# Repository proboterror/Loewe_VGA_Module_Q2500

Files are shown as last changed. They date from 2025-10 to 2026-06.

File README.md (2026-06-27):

# Loewe TVs Q2500 VGA Module
Recreation of VGA module PCB for Loewe TVs with Q2500M chassis.

Project based on work done by Oelii from [circuit-board.de/forum](https://circuit-board.de/forum/index.php/Thread/28516-WIP-DIY-Loewe-VGA-Modul-Q2500/)

Schematic recreated from the scratch in KiCad. PCB based on Oelii's layout and verified with Desing/Electrical Rules Checker tools.<br>
Components footprints replaced with KiCad standard ones.

## Chassis compatibility
Unverified, obtained from post by djcalle on [circuit-board.de/forum](https://circuit-board.de/forum/index.php/Thread/28516-WIP-DIY-Loewe-VGA-Modul-Q2500/?postID=906980#post906980):
- Q23, Q24, Q25 can accept VGA cards.
- Q25 and Q24 use the same VGA card (only 2 differences: cable length and 150R termination on RGB lines.)
- Q25 seems to be inconsistent with VGA card compatibility.
- Q24 seems consistent with vga card compatibility.
- Q23 uses its own [different card](https://github.com/proboterror/Loewe_VGA_Module_Q2300).

## EDID option
For widescreen TVs [EDID](https://en.wikipedia.org/wiki/Extended_Display_Identification_Data) EEPROM option can be installed and flashed, helping to automatically add 848x480@60Hz (CVT) default widescreen resolution.

Original schematic from [Loewe Q2500-M chassis service manual](doc/Q2500-M/Loewe%20Q2500M%20Service%20Manual.pdf)
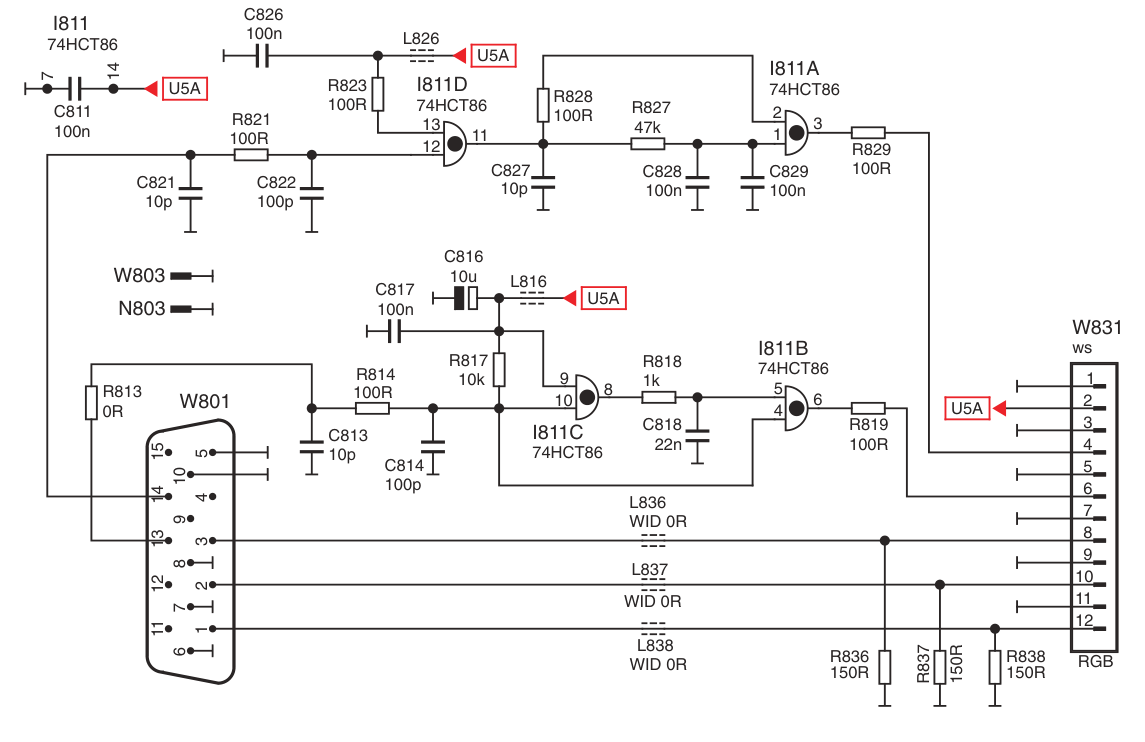
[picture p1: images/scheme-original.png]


Recreated schematic and PCB
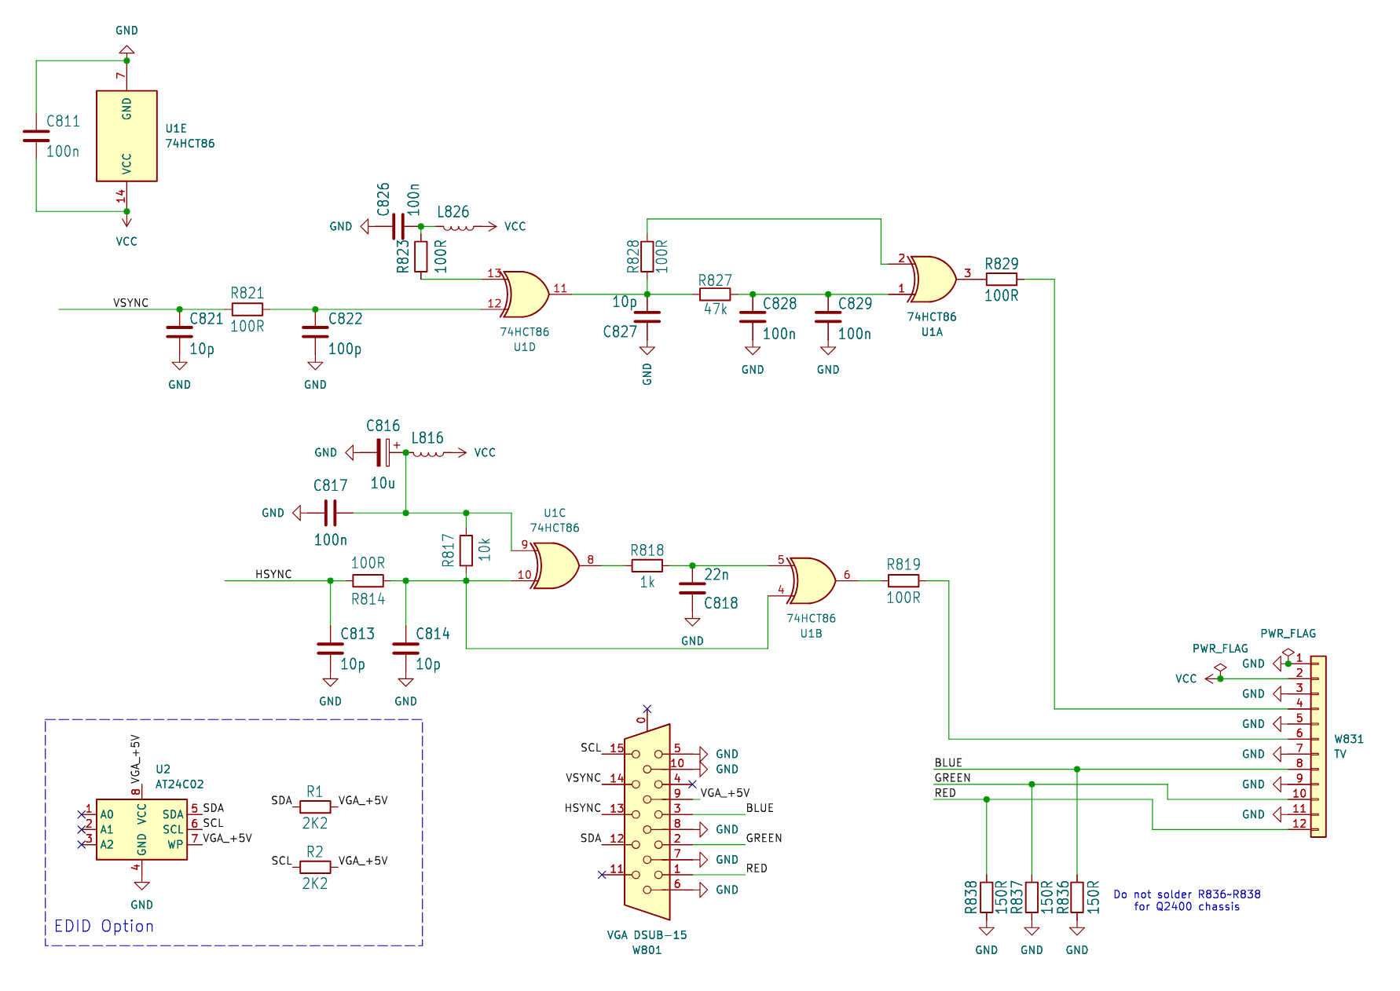
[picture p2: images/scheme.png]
scheme

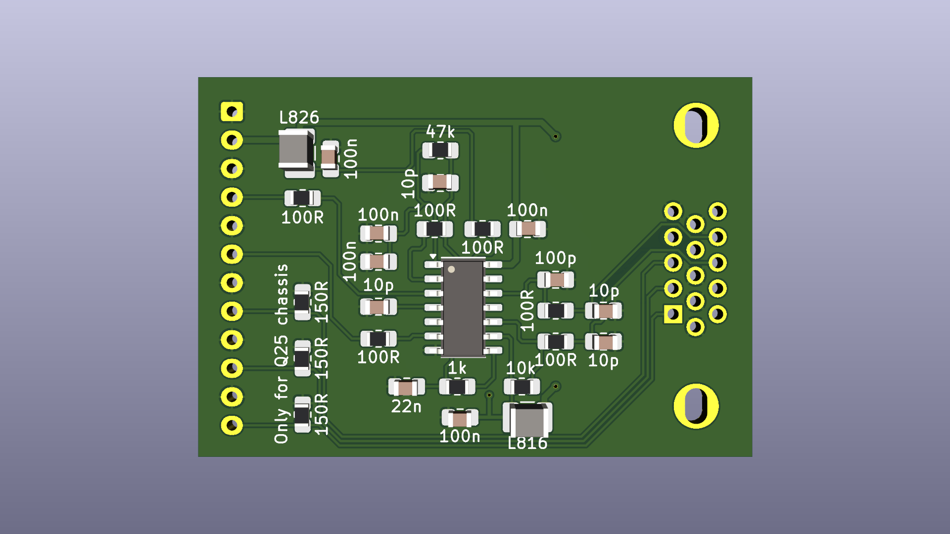
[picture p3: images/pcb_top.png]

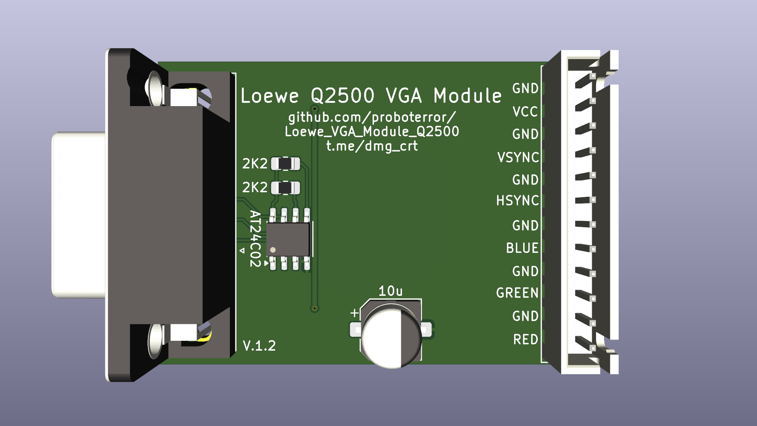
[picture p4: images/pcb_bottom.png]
pcb_bottom

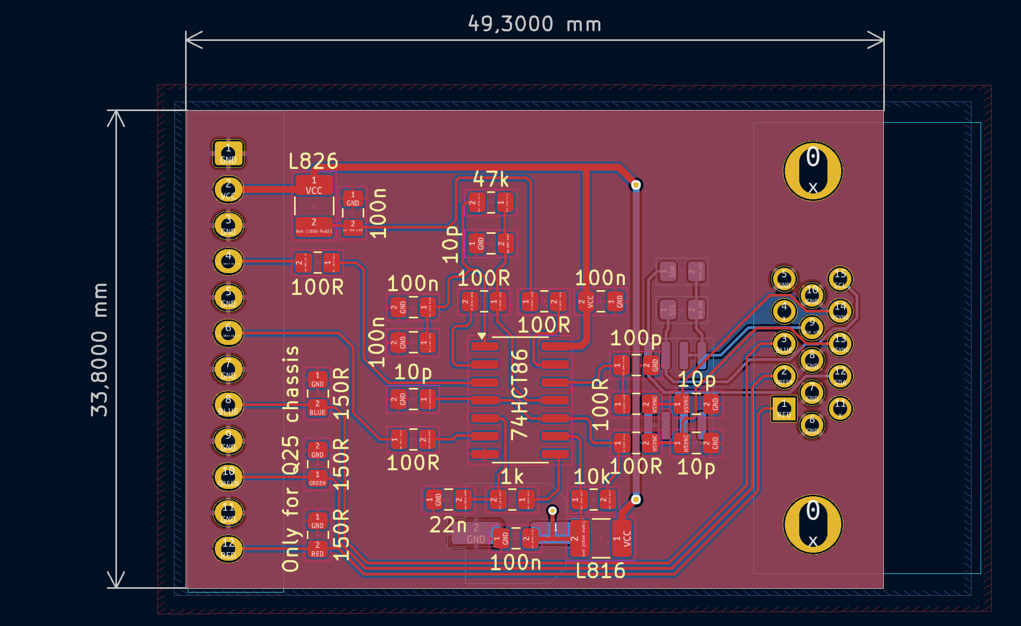
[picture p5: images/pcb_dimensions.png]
pcb_dimensions


## Bill of materials
|Reference|Value|Footprint|Qty|
|-----|-----|-----|-----|
|C811,C817,C826,C828,C829|100n|0805|5|
|C813,C814,C821,C827|10p|0805|4|
|C816|10u|0805|1|
|C818|22n|0805|1|
|C822|100p|0805|1|
|L816,L826|1210(3225)|4.7uH|2|
|R814,R819,R821,R823,R828,R829|100R|0805|6|
|R817|10k|0805|1|
|R818|1k|0805|1|
|R827|47k|0805|1|
|R836,R837,R838|150R|0805|3|
|I811|74HCT86|SO-14|1|
|W801|VGA DSUB-15<br>Edge pin offset 8.35mm<br>Mounting holes offset 10.89mm ||1|
|W831|JST XH 2.54 12 Pin||1|
|U2|AT24C02 (EDID option)|SOIC-8|1|
|R1,R2|2K2 (EDID option)|0805|2|

## Order boards from manufacturer
Send "gerbers" folder content packed to zip archive.

## Build Notes
AT24C02 EEPROM and R1,R2 are EDID option, useful for connection widescreen models to PC/VGA.

L816 and L826 SMD 1210(3225) inductors value are unknown; 4.7uH in Q2300 VGA module schematic; can be replaced with 0R resistor.

W831 connector originally is Molex 22-23-2121. Probably can be replaced with XH 2.54 12 pin connectors / cables, note pins step 2.5/254 mm.<br>
Pay attention on cable connectors type: same direction or reverse direction.<br>
12 pin 50 cm cable are required for Q25 chassis, 30 cm cable for Q24 chassis. For Q23 chassis, two 10 pin cables are required.

**Double-check ground and VCC connection on VGA module PCB and TV chassis before soldering 12-pin W831 connector and power on.**

## EDID ROM
[Extended Display Identification Data (EDID)](https://en.wikipedia.org/wiki/Extended_Display_Identification_Data) ROM sends display info to PC over VGA [I2C](https://en.wikipedia.org/wiki/I2C) [DDC (Display Data Channel)](https://en.wikipedia.org/wiki/Display_Data_Channel), such as supported / default resolutions, supported frequency ranges, physical dimensions and display name.

Standard VGA resolutions 640x400@70Hz and 640x480@60Hz marked as supported.<br>
Added custom default resolution 848x480@60Hz.<br>
Added modeline generated with [CVT](doc/VESA-CVT-1.2.pdf) formulas.<br>
Display reported as "Loewe CRT".

Generated [edid.bin](EDID/edid.bin) can be in-system programmed to AT24C02 EEPROM with CH341 (I2C) programmer, 8 pin chip clip and NeoProgrammer V2.2.0.10:
"IC/I2C/Generic/_24C02 [3.3V]" or "Detect", "File/Open" .bin, "Write IC" (Erase, Blank Check, Write, Verify).

[EDID 1.3](doc/VESA-EEDID-A1.pdf) display description ROM image in raw .hex format generated with [generate_edid.py](EDID/generate_edid.py) script.

Generate edid.hex:
```
python generate_edid.py > edid.hex
```
Convert raw .hex to .bin:
```
type edid.hex | xxd -r -p > edid.bin
```
To view generated display description:
```
edid-decode edid.bin
```

Conservative / more compatible custom modeline included by default:
```
Modeline "848x480_60" 31.75  848 864 944 1024  480 483 493 517 -hsync +vsync
```
Alternative modeline generated with cvt utility can be selected in generate_edid.py:
```
cvt 848 480 60
Modeline "848x480_60" 31.50  848 872 952 1056  480 483 493 500 -hsync +vsync
```

## Install
Q2400 chassis:
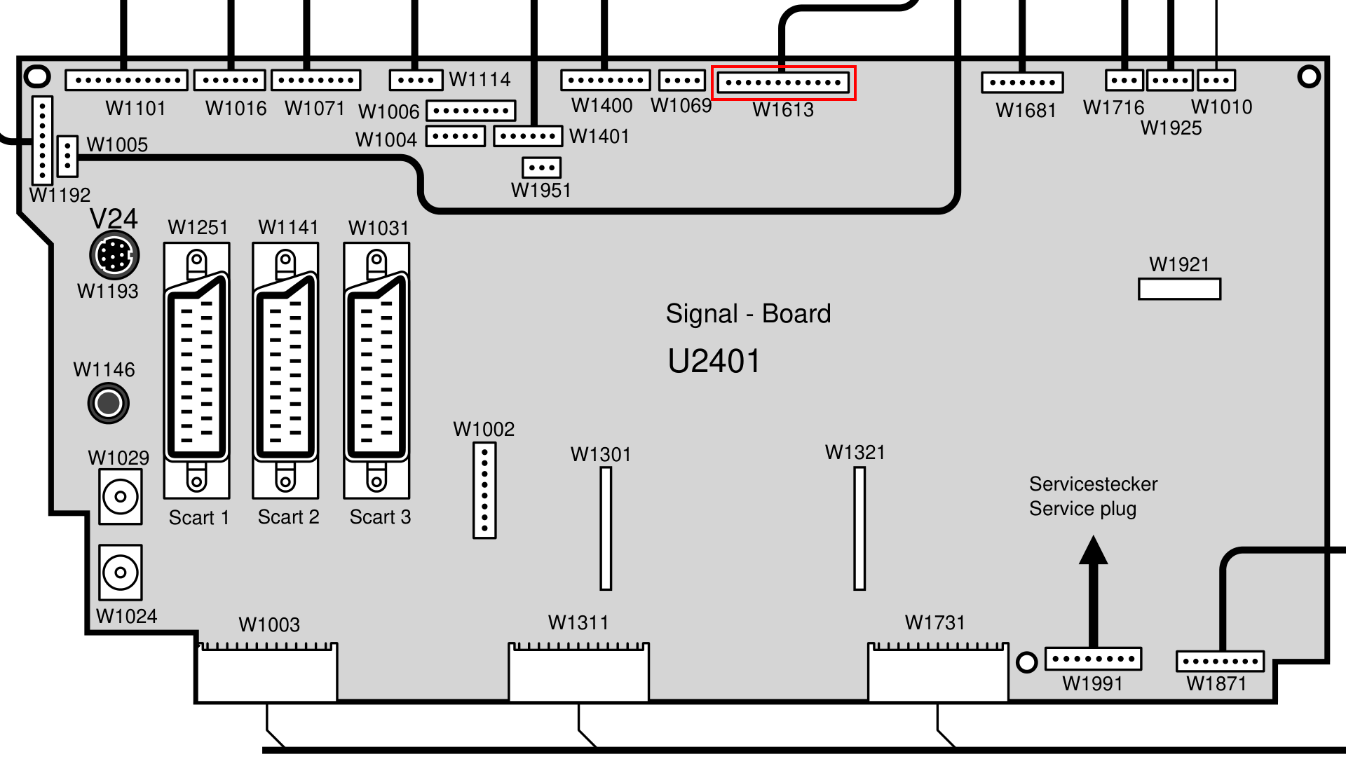
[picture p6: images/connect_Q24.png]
Q2400 Module connection diagram


Q2500 chassis:
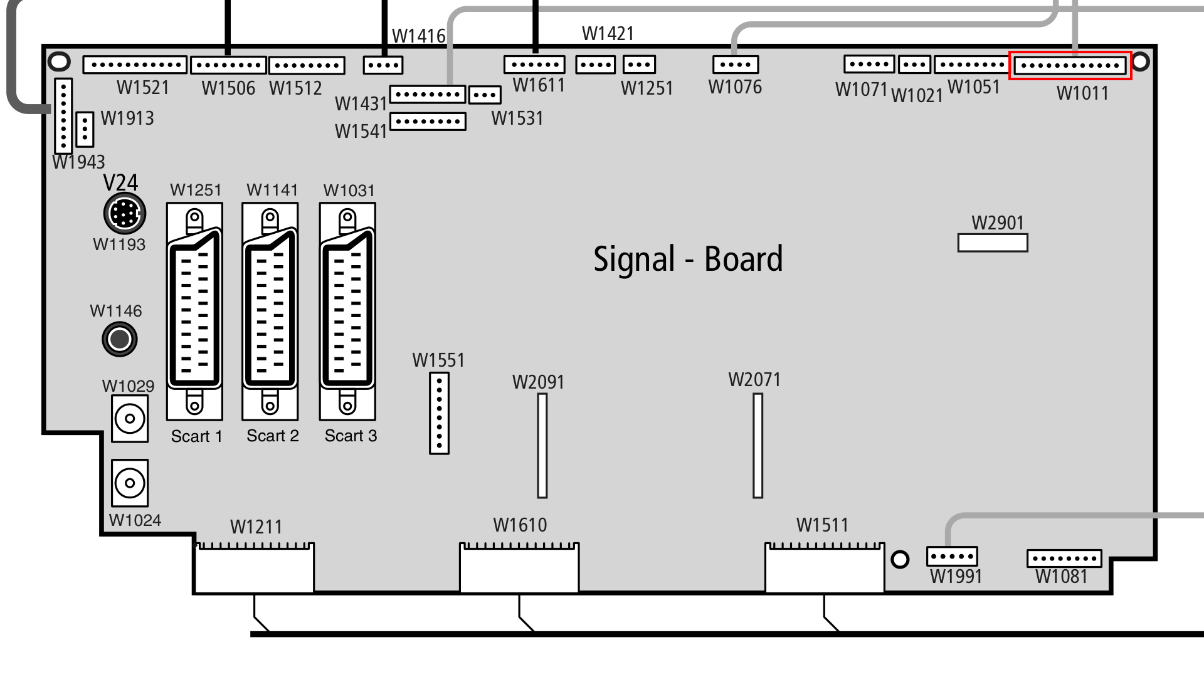
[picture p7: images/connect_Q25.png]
Q2500 Module connection diagram


## Required TV and adapter board modifications
Mods information provided by @neonname.

Combined VGA adapter board output and TV input termination/load resistance for RGB lines should be ~75 Ohm.

### Q2400
TV Signal Board schematic:
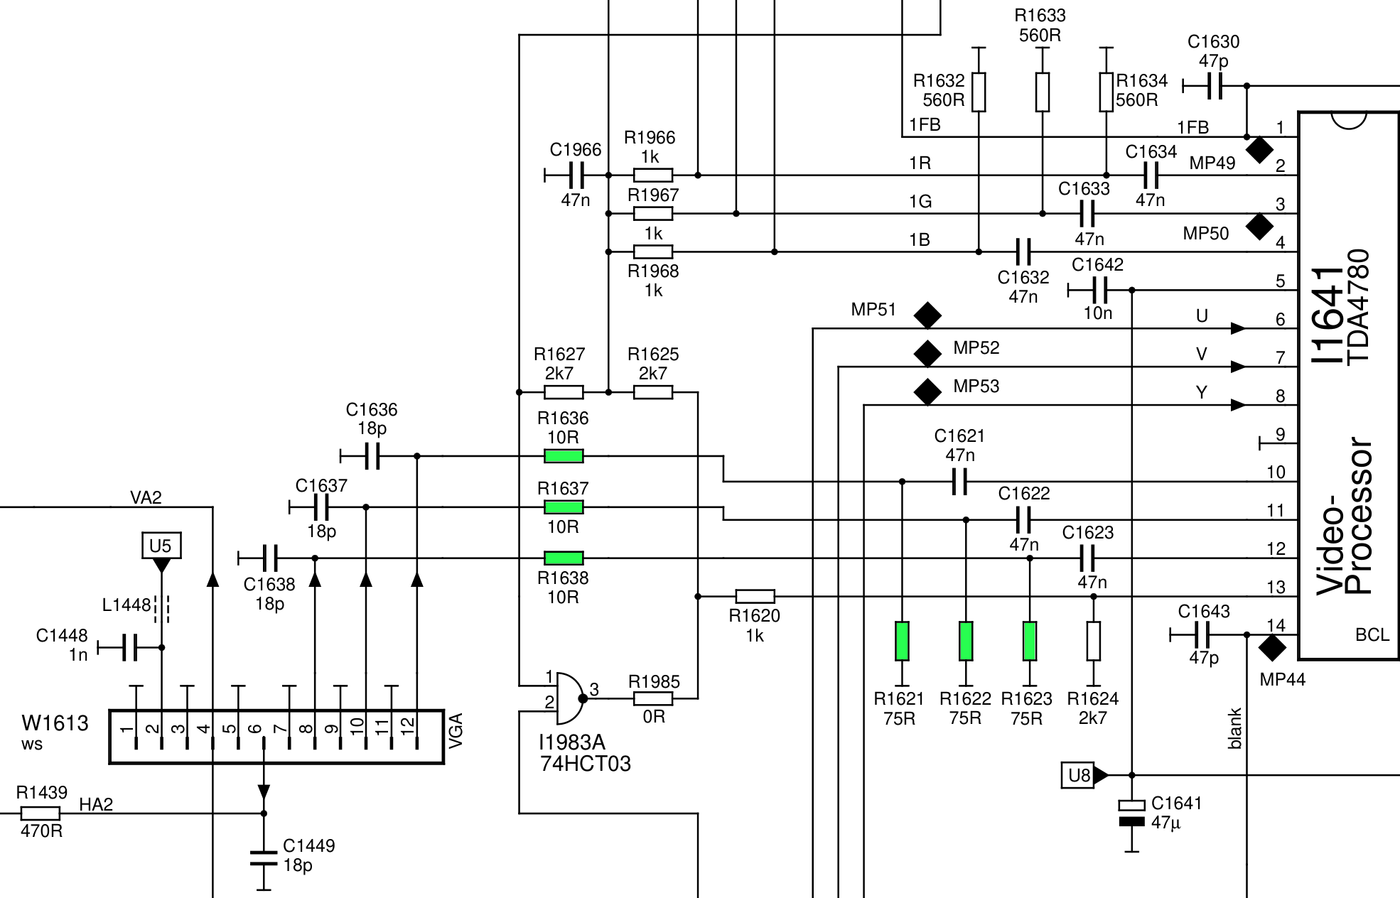
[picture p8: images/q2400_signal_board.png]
Q2400 Signal Board schematic

PCB components side:
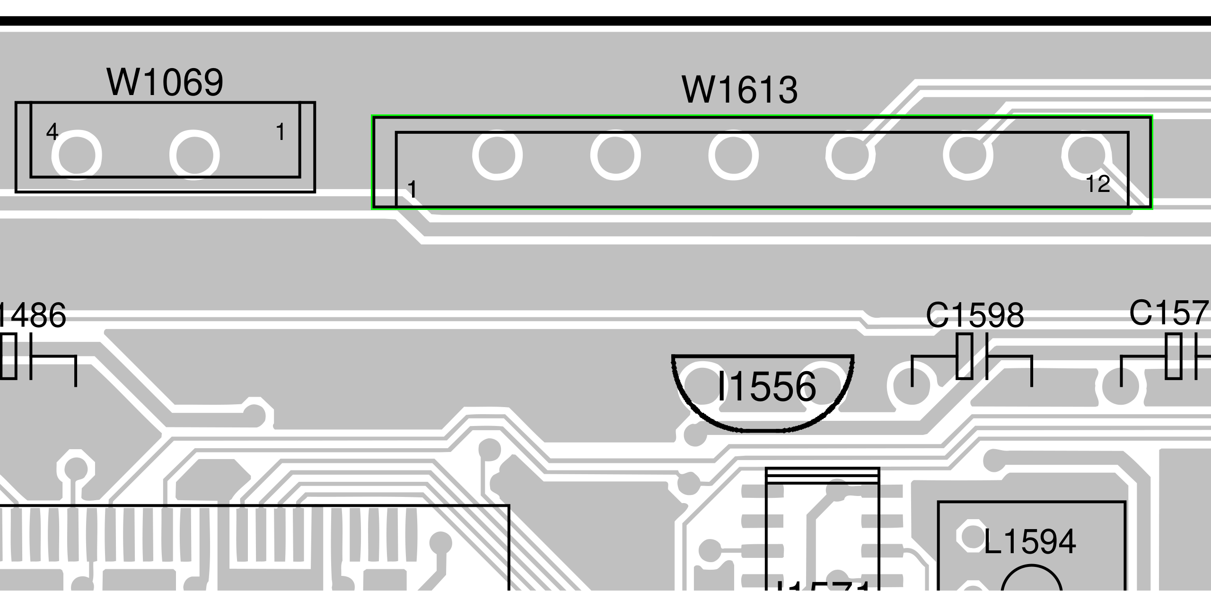
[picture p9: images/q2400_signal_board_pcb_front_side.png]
Q2400 Signal Board PCB

Q2400 signal board already have 75 Ohm termination resistors on RGB lines.<br>
150 Ohm RGB termination resistors on adapter board should be removed.
<hr>

### Q2500-B
TV Signal Board schematic:
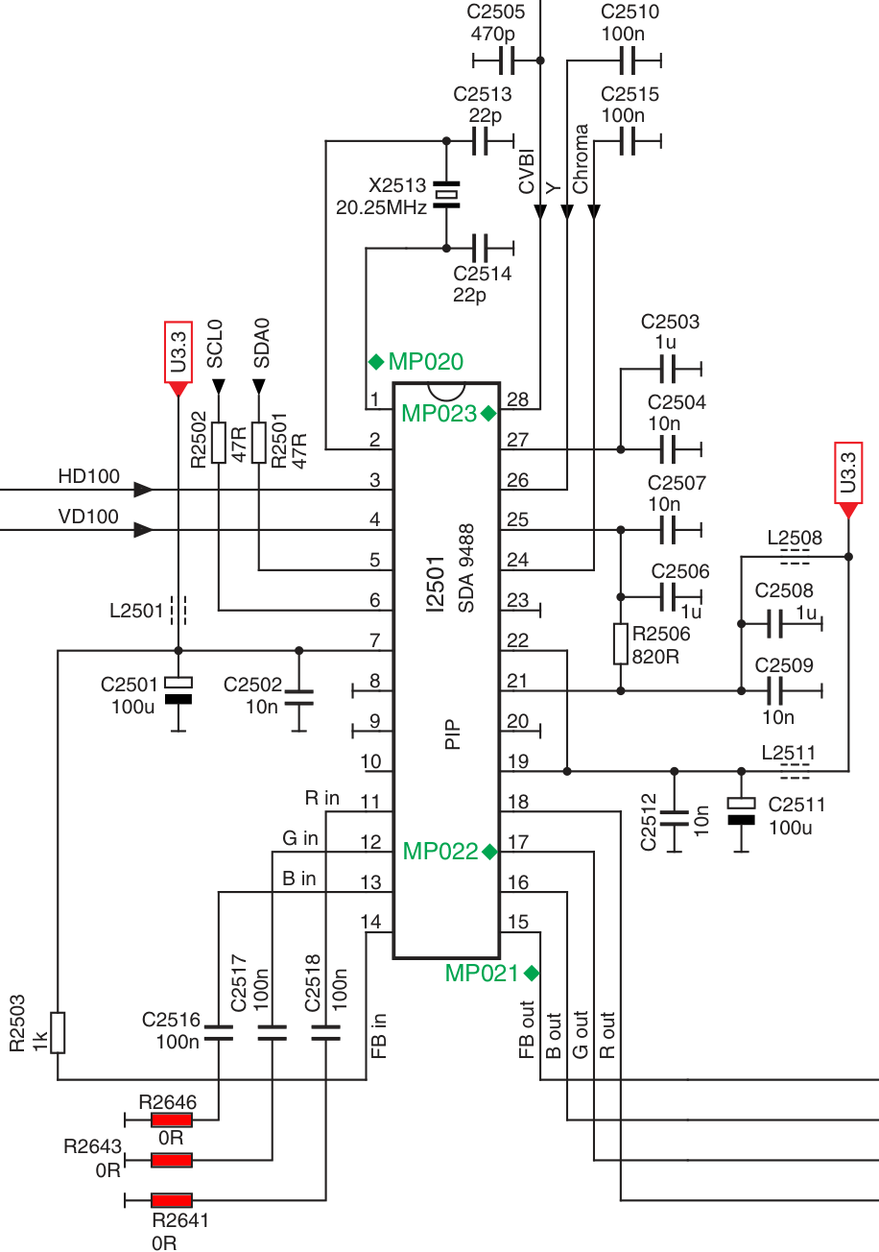
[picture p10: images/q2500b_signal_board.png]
Q2500-B Signal Board schematic

PCB components side:
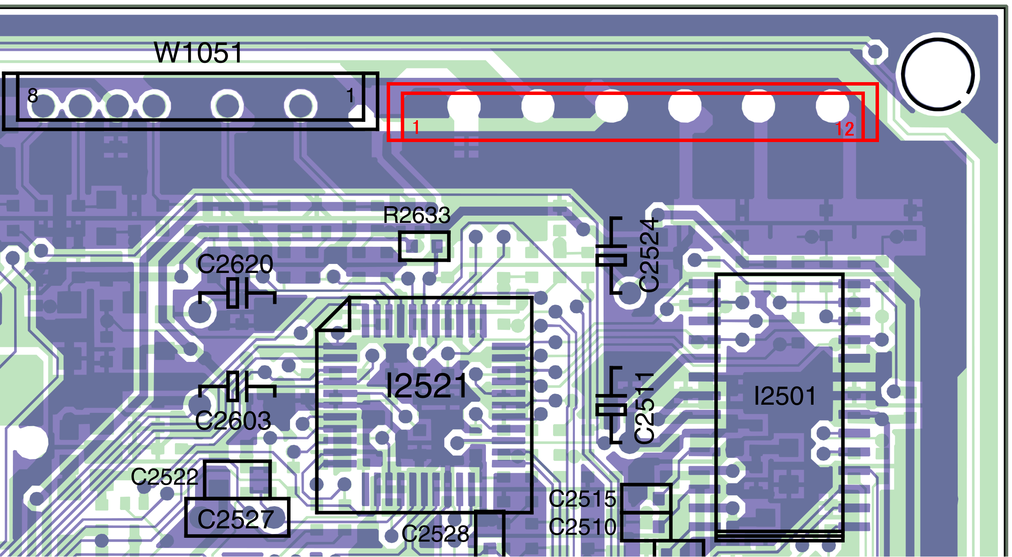
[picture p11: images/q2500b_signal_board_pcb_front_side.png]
Q2500-B Signal Board PCB

PCB solder side:
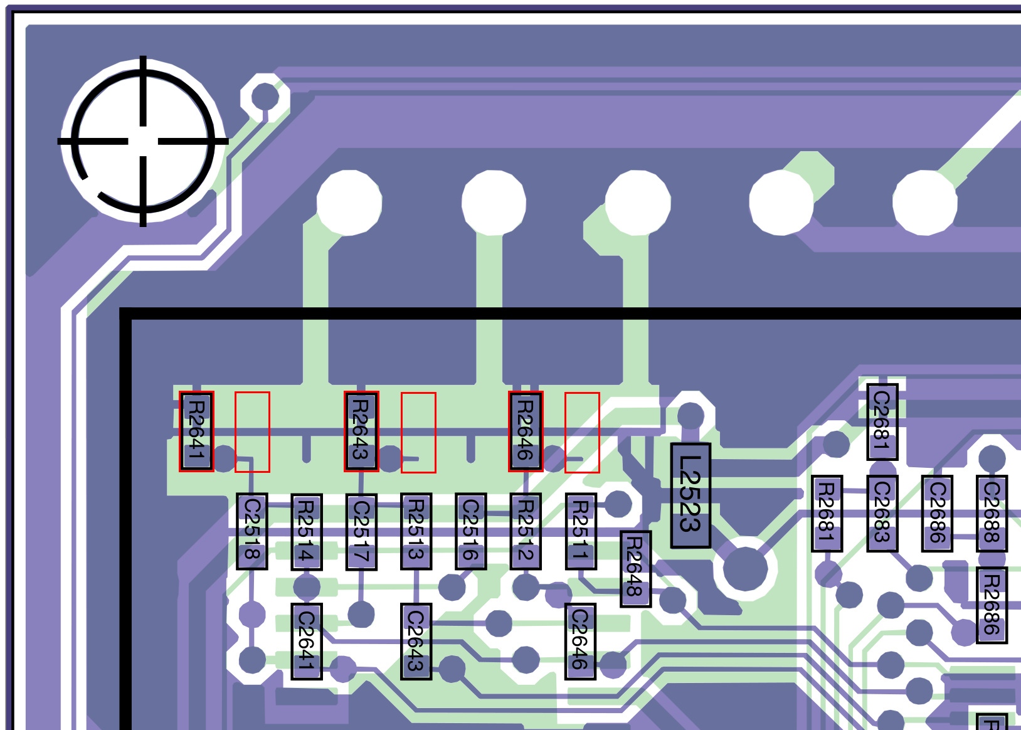
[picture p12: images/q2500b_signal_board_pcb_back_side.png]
Q2500-B Signal Board PCB

PCB missing W1011 VGA connector and RGB input resistors, RGB input connected to ground with 0R load resistors.<br>
Suggested changes, needs to check on real board:<br>
- Replaсe R2641, R2643, R2646 (0R) with 27R, add missing R1016, R1017, R1018 47R resistors (like Q2500-M) (probably incorrect termination)
- Or replaсe R2641, R2643, R2646 (0R) with 150R; add missing R1016, R1017, R1018 (0R) (like Q2500-H). Note: R2512, R2513, R2514.
<hr>

### Q2500-H
TV Signal Board schematic:
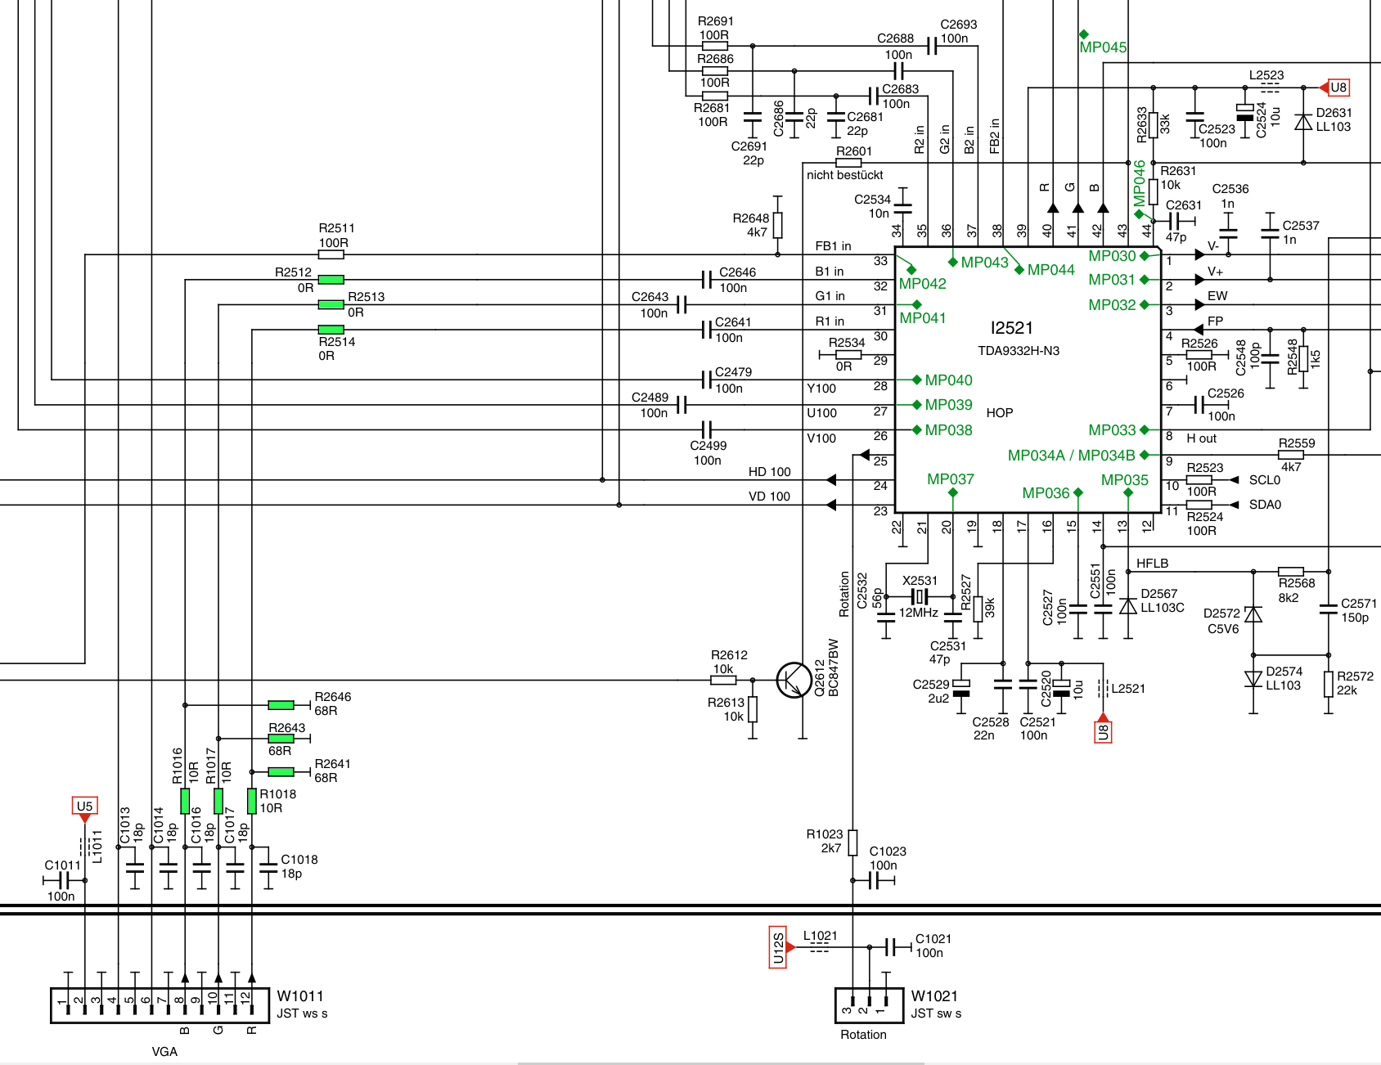
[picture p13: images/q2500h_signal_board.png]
Q2500-H Signal Board schematic

PCB components side:
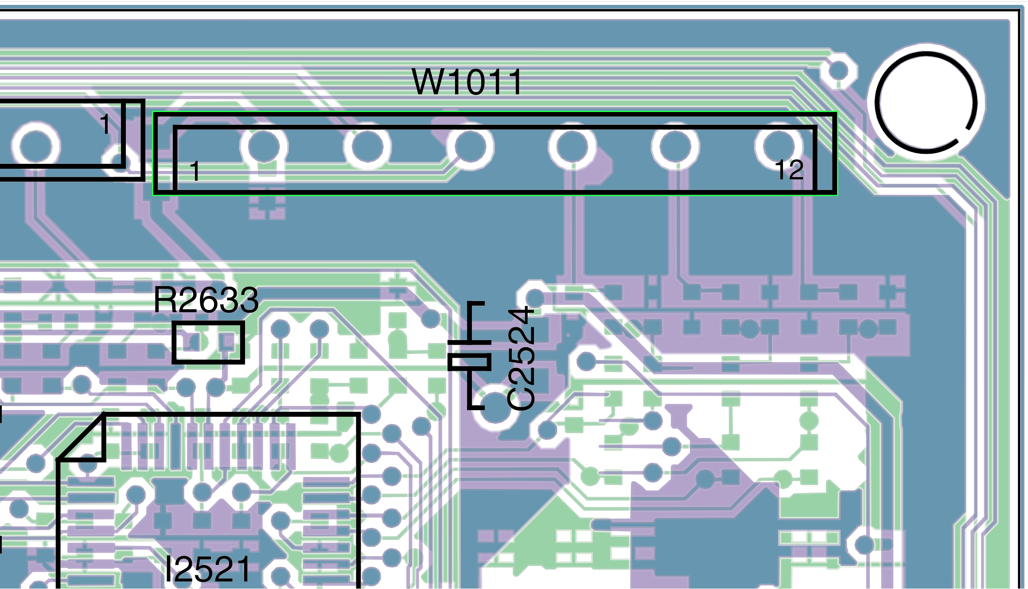
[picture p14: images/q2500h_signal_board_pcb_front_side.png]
Q2500-H Signal Board PCB

PCB solder side:
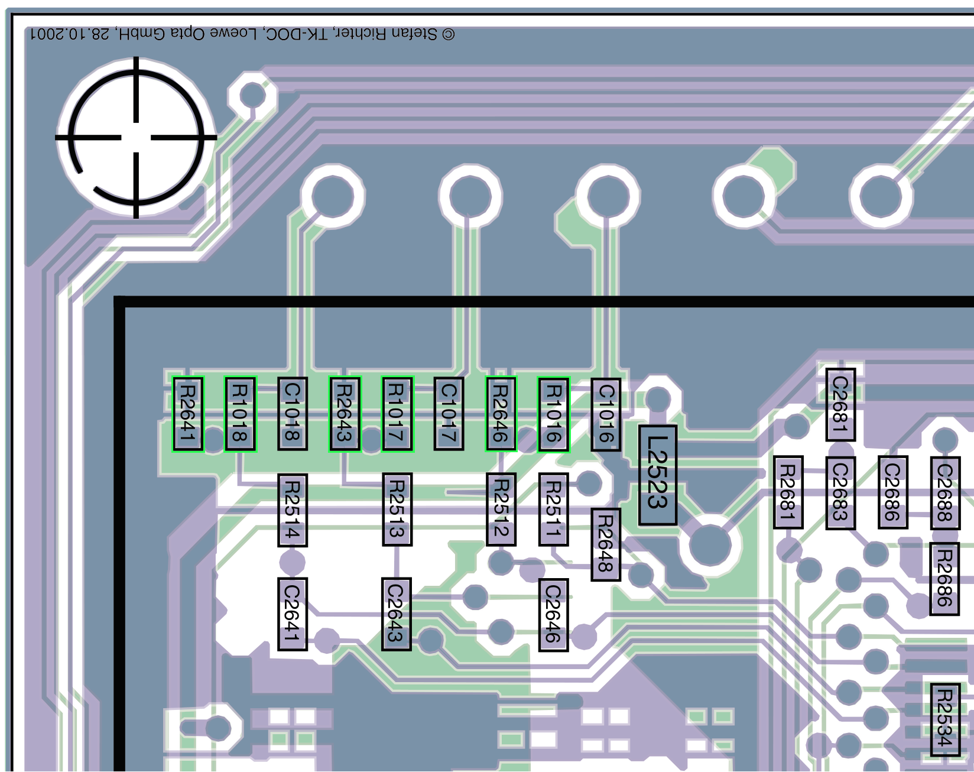
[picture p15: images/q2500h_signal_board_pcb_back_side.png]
Q2500-H Signal Board PCB

Recommended changes:<br>
- Replaсe R2641, R2643, R2646 (68R) with 150R; R1016, R1017, R1018 (10R) with 0R; R2512, R2513, R2514 (0R) with 47R; remove C1016, C1017, C1018.
<hr>

### Q2500-M
TV Signal Board schematic:
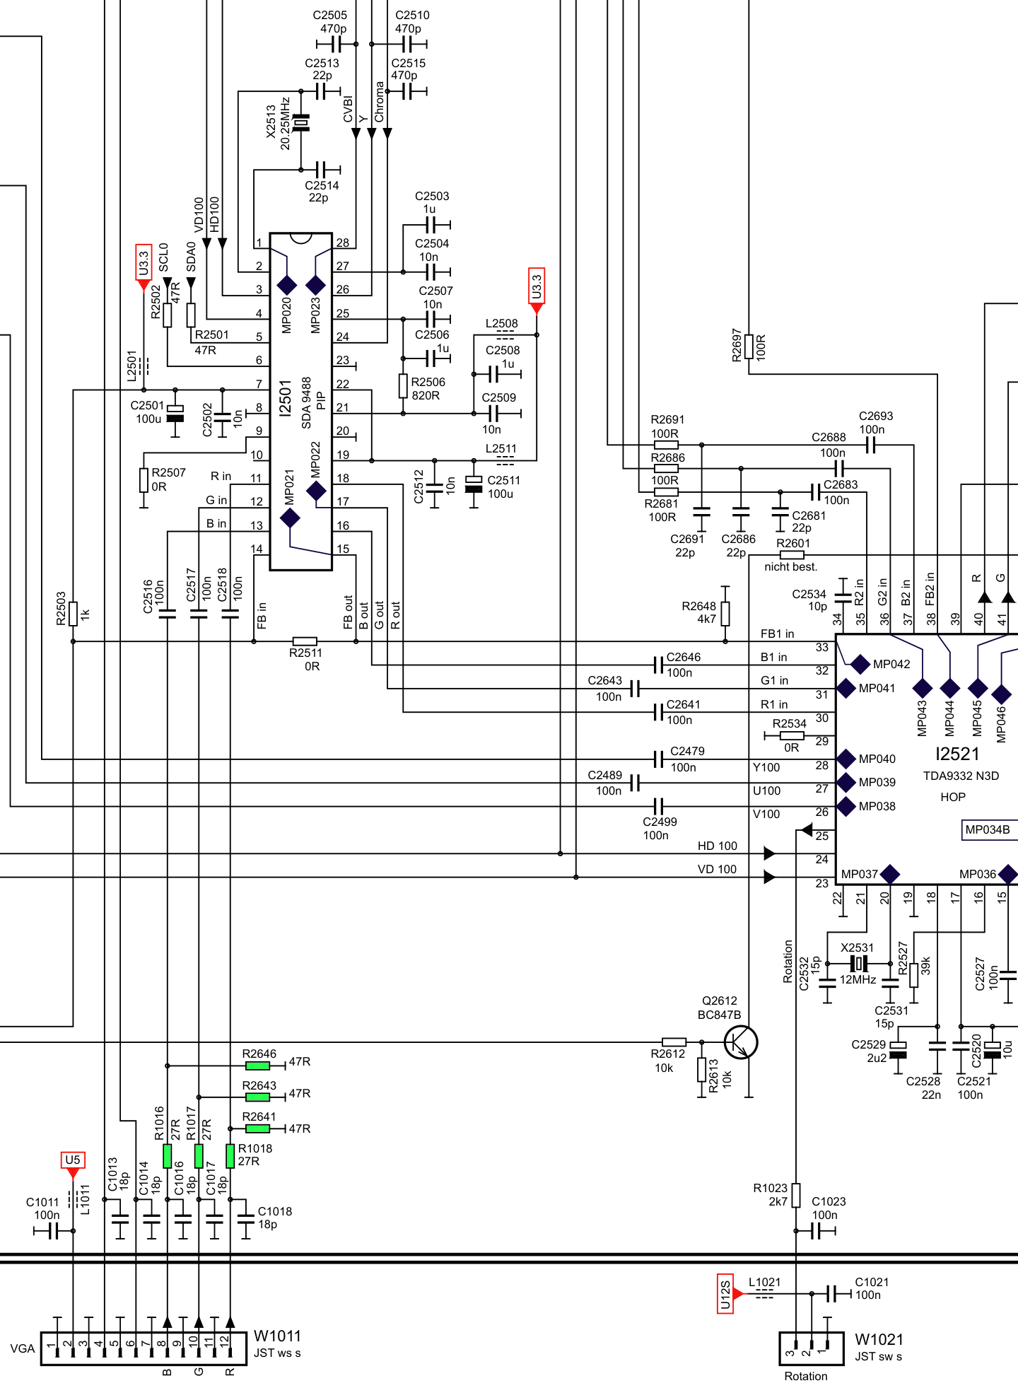
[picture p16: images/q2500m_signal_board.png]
Q2500-M Signal Board schematic

PCB components side:
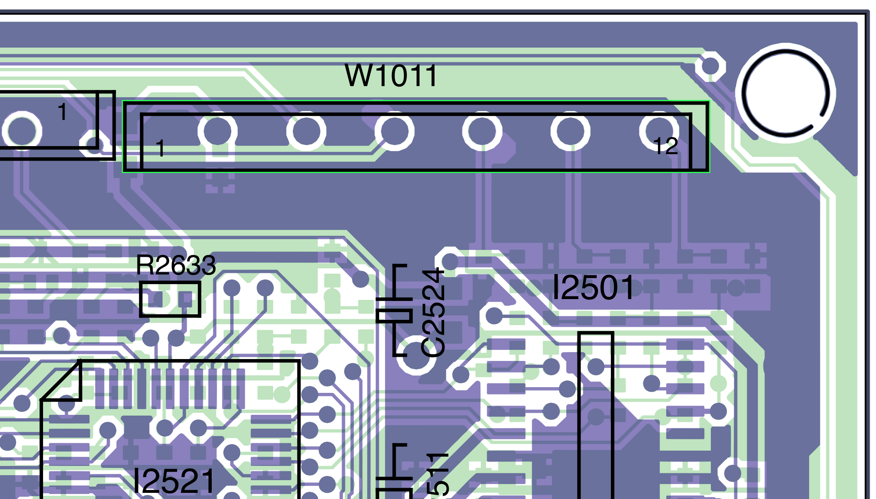
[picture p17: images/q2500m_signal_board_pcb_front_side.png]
Q2500-M Signal Board PCB

PCB solder side:
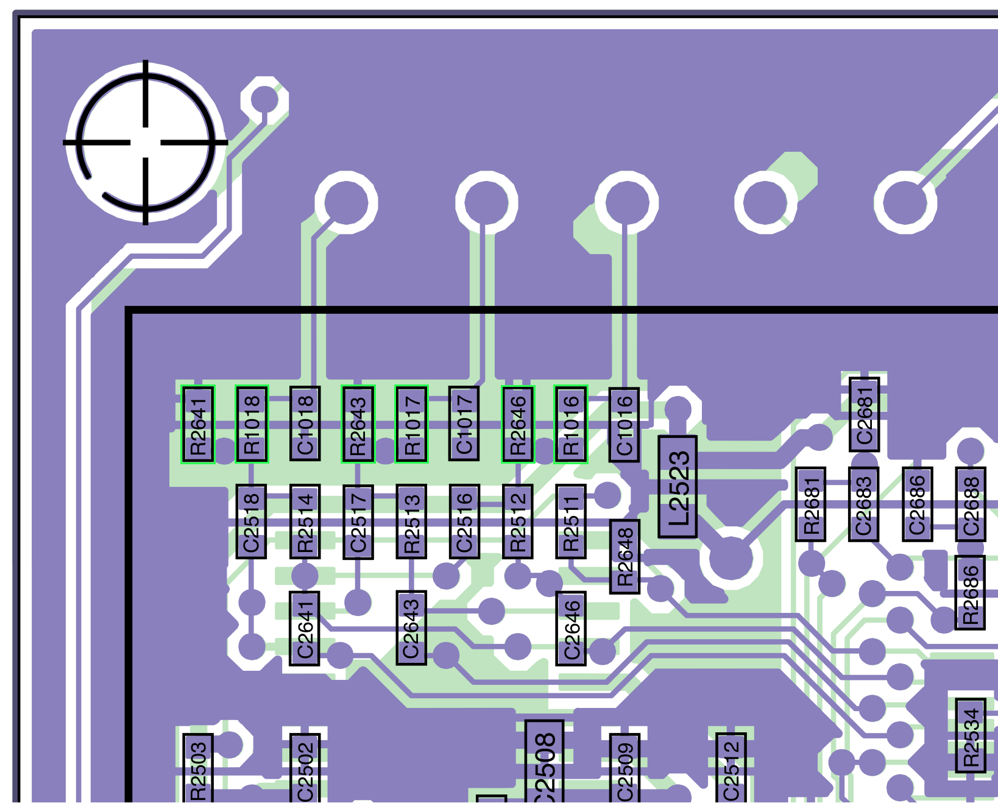
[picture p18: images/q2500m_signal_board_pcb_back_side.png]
Q2500-M Signal Board PCB

Suggested changes, needs to check on real board:<br>
- Replaсe R2641, R2643, R2646 (47R) with 150R; R1016, R1017, R1018 (27R) with 0R; remove C1016, C1017, C1018. Note: R2512, R2513, R2514.
<hr>

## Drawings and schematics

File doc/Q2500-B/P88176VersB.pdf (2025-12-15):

I1731 | I1771

R1811

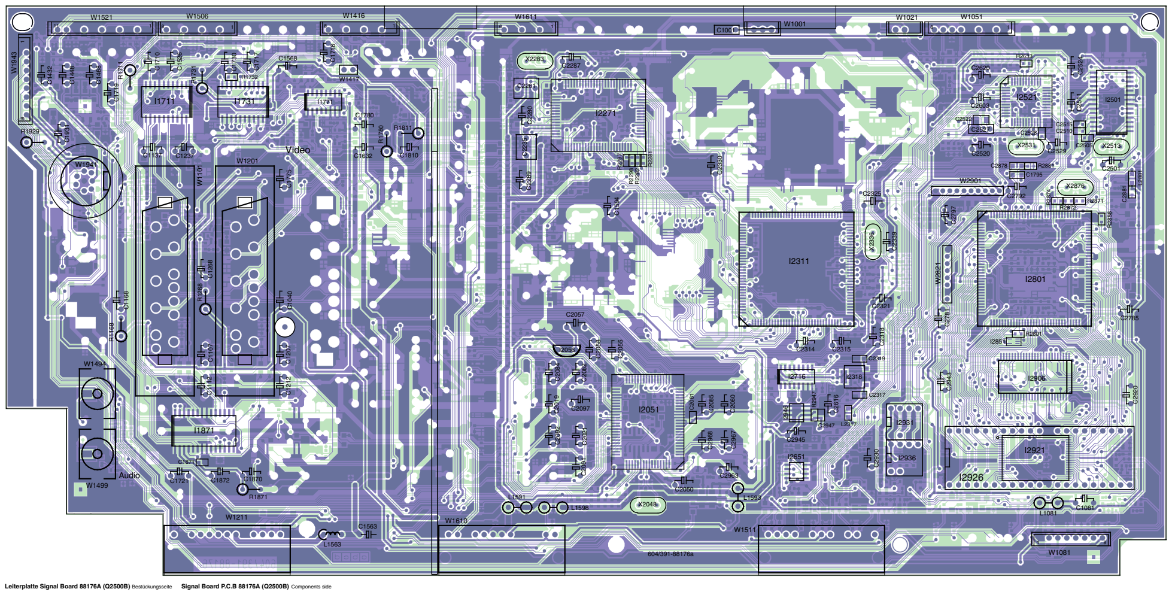
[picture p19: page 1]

Q1922

Q1912

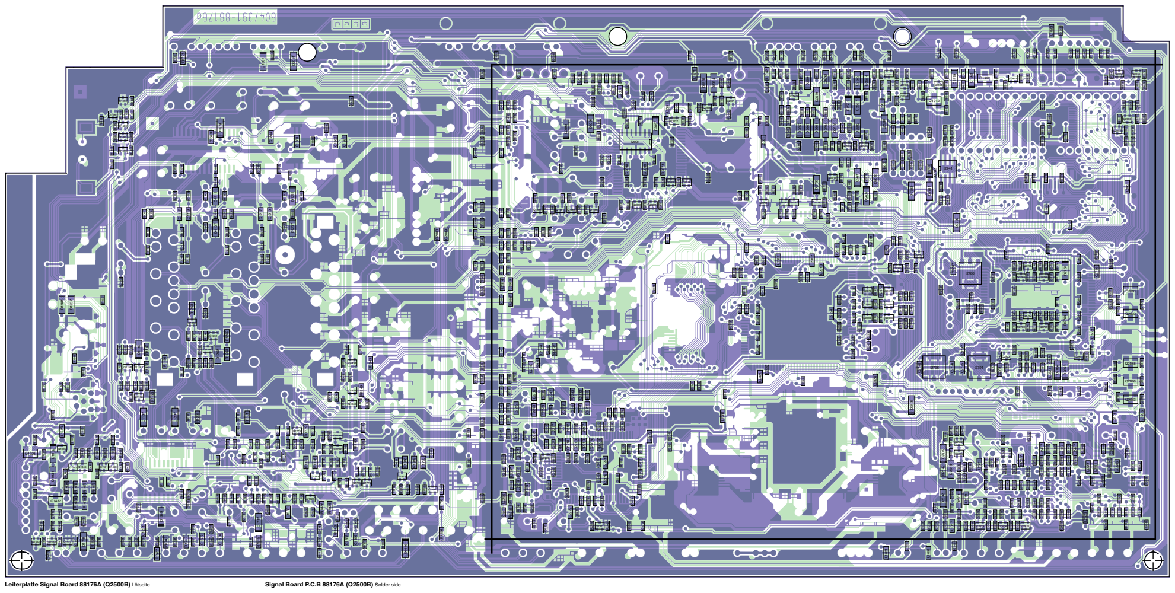
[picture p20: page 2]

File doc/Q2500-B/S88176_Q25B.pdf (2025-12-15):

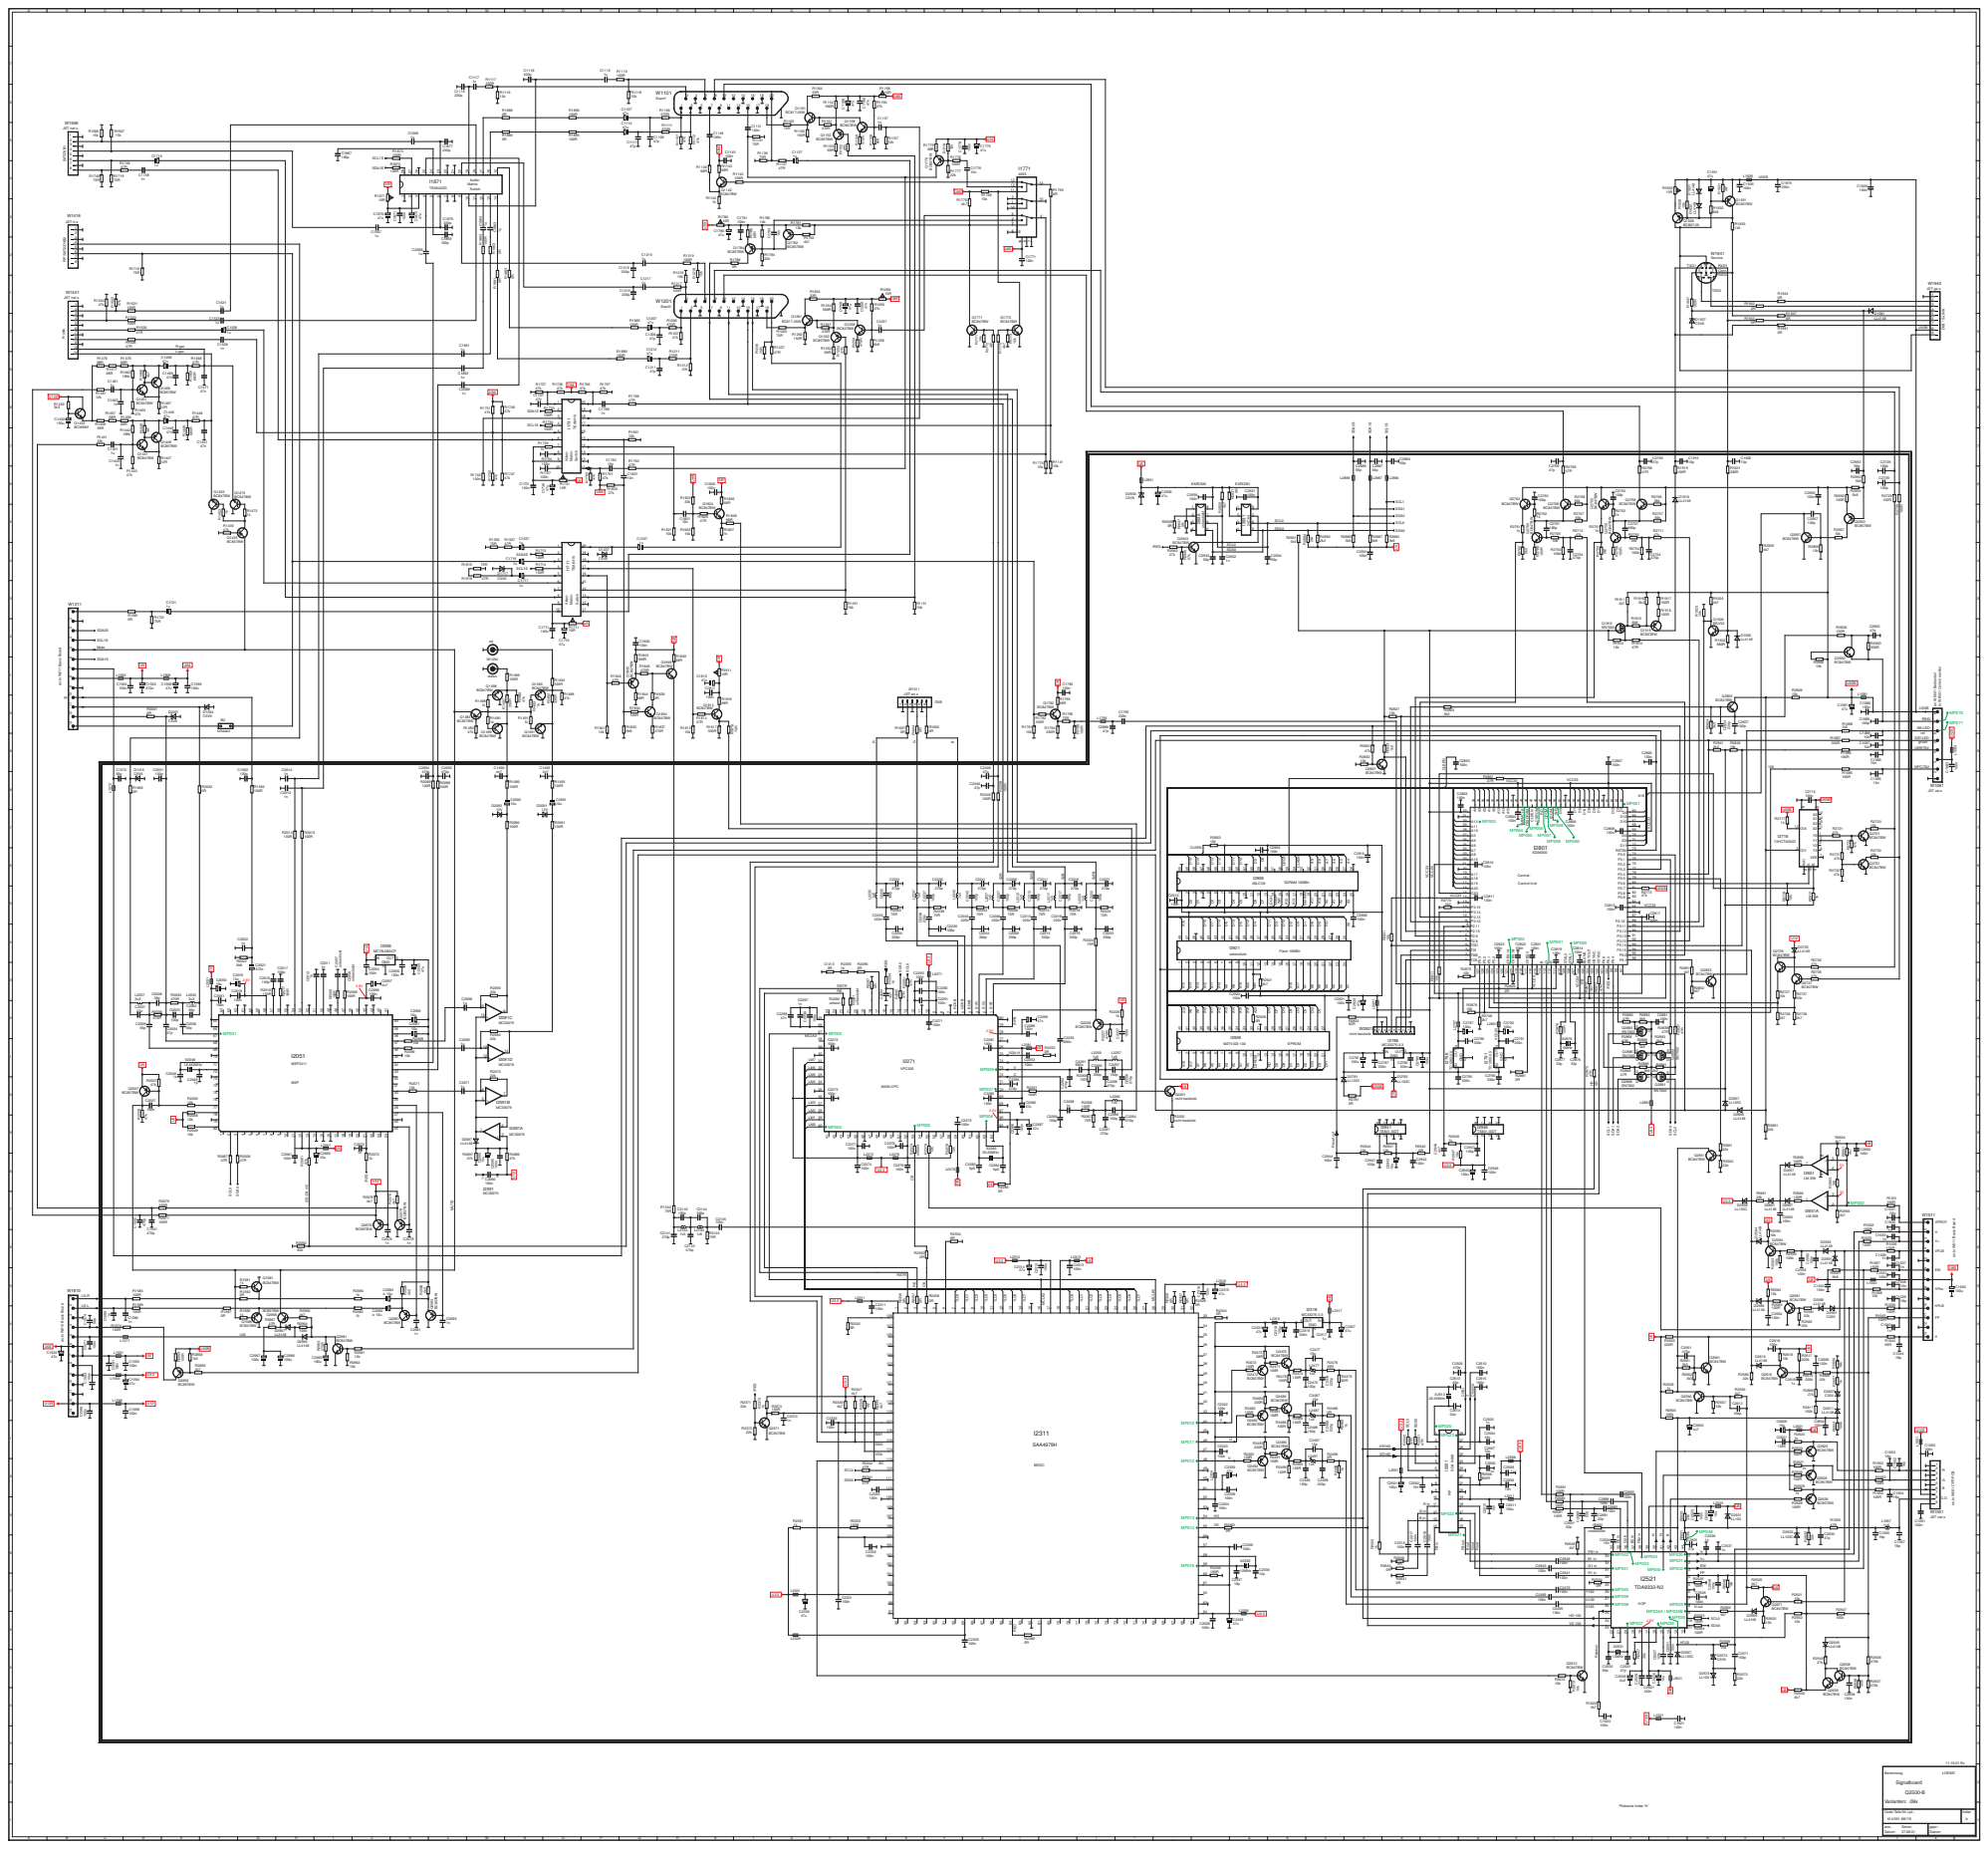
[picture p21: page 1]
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

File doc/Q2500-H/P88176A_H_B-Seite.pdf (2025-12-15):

# Video

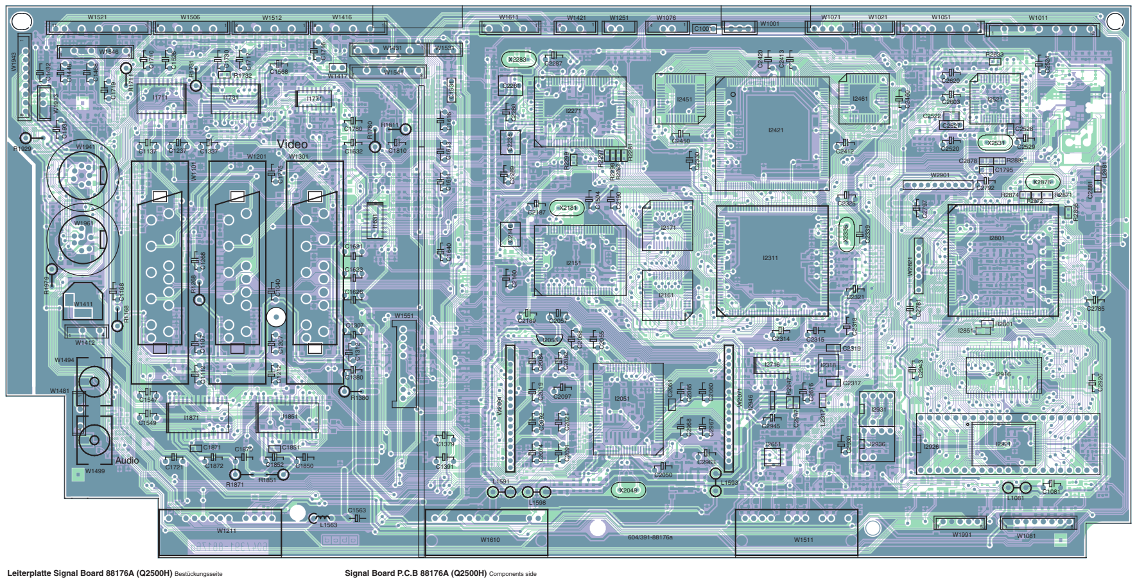
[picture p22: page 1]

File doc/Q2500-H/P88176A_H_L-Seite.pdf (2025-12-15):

I2091

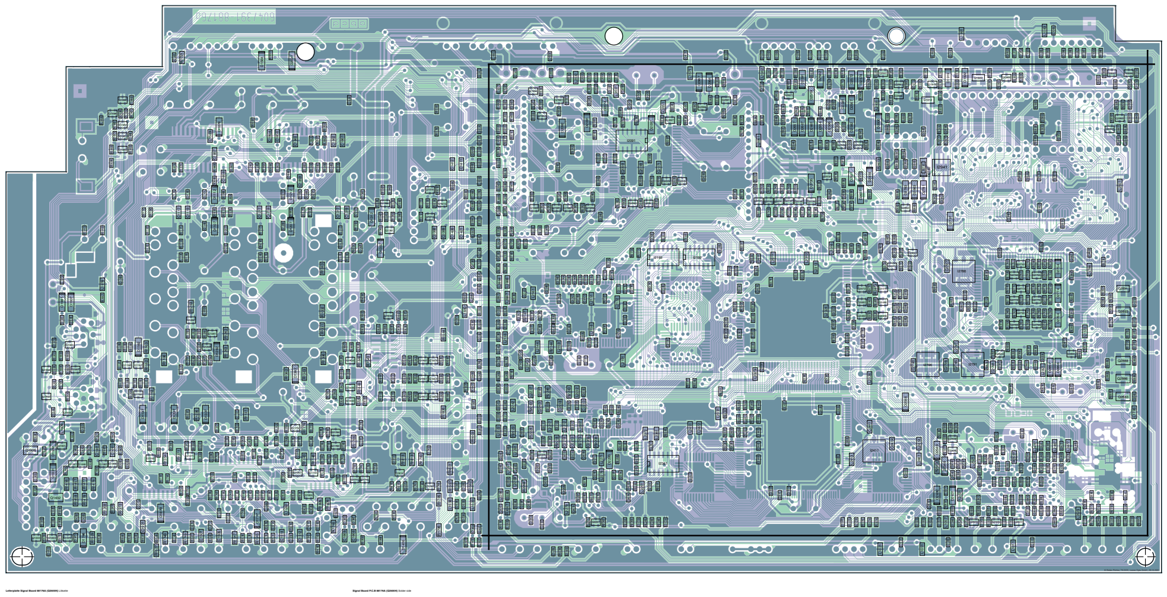
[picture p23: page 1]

© Stefan Richter, TK-DOC, Loewe Opta GmbH, 28.10.2001

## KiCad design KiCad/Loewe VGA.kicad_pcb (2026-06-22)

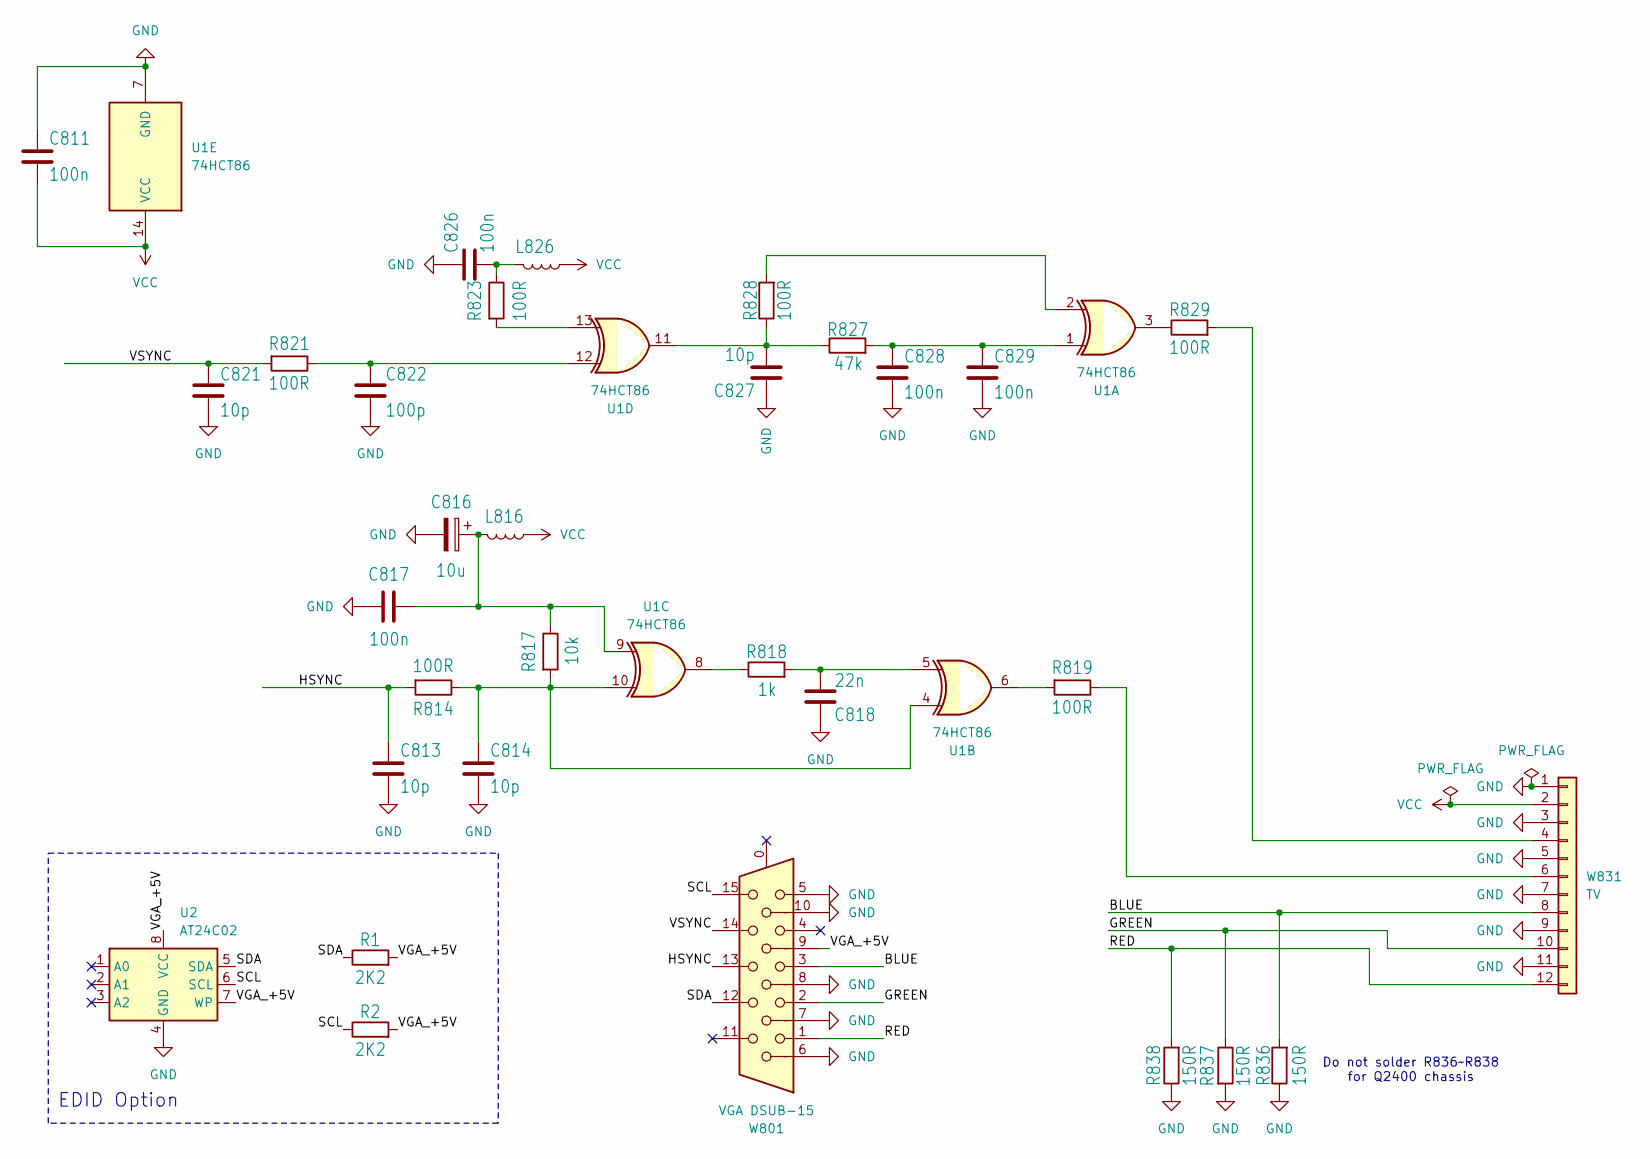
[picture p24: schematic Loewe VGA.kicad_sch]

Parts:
C811, C817, C826, C828, C829: 100n; C_0805_2012Metric_Pad1.18x1.45mm_HandSolder
C813, C814, C821, C827: 10p; C_0805_2012Metric_Pad1.18x1.45mm_HandSolder
C816: 10u; CP_Elec_6.3x5.3
C818: 22n; C_0805_2012Metric_Pad1.18x1.45mm_HandSolder
C822: 100p; C_0805_2012Metric_Pad1.18x1.45mm_HandSolder
L816, L826: 4u7; L_1210_3225Metric_Pad1.42x2.65mm_HandSolder
R1, R2: 2K2; R_0805_2012Metric_Pad1.20x1.40mm_HandSolder
R814, R819, R821, R823, R828, R829: 100R; R_0805_2012Metric_Pad1.20x1.40mm_HandSolder
R817: 10k; R_0805_2012Metric_Pad1.20x1.40mm_HandSolder
R818: 1k; R_0805_2012Metric_Pad1.20x1.40mm_HandSolder
R827: 47k; R_0805_2012Metric_Pad1.20x1.40mm_HandSolder
R836, R837, R838: 150R; R_0805_2012Metric_Pad1.20x1.40mm_HandSolder
U1: 74HCT86; SO-14_3.9x8.65mm_P1.27mm
U2: AT24C02; SOIC-8_3.9x4.9mm_P1.27mm
W801: VGA DSUB-15; DSUB-15-HD_Female_Horizontal_P2.29x1.98mm_EdgePinOffset3.03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
W831: TV; JST_XH_B12B-XH-A_1x12_P2.54mm_Vertical

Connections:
/BLUE: R836.2, W801.3, W831.8
/GREEN: R837.1, W801.2, W831.10
/HSYNC: C813.1, R814.2, W801.13
/RED: R838.2, W801.1, W831.12
/SCL: R2.1, U2.6 (SCL), W801.15
/SDA: R1.1, U2.5 (SDA), W801.12
/VGA_+5V: R1.2, R2.2, U2.7 (WP), U2.8 (VCC), W801.9
/VSYNC: C821.1, R821.2, W801.14
GND: C811.1, C813.2, C814.2, C816.2, C817.1, C818.1, C821.2, C822.2, C826.1, C827.1, C828.2, C829.2, R836.1, R837.2, R838.1, U1.7 (GND), U2.4 (GND), W801.5, W801.6, W801.7, W801.8, W801.10, W831.1, W831.3, W831.5, W831.7, W831.9, W831.11
unnamed: C814.1, R814.1, R817.2, U1.4, U1.10
unnamed: C816.1, C817.2, L816.2, R817.1, U1.9
unnamed: C818.2, R818.2, U1.5
unnamed: C822.1, R821.1, U1.12
unnamed: C826.2, L826.2, R823.1
unnamed: C827.2, R827.1, R828.1, U1.11
unnamed: C828.1, C829.1, R827.2, U1.1
unnamed: R818.1, U1.8
unnamed: R819.2, U1.6
unnamed: R823.2, U1.13
unnamed: R828.2, U1.2
unnamed: R829.1, U1.3
unnamed: R829.2, W831.4
unnamed: R819.1, W831.6
VCC: C811.2, L816.1, L826.1, U1.14 (VCC), W831.2

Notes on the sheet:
EDID Option
Do not solder R836~R838 for Q2400 chassis

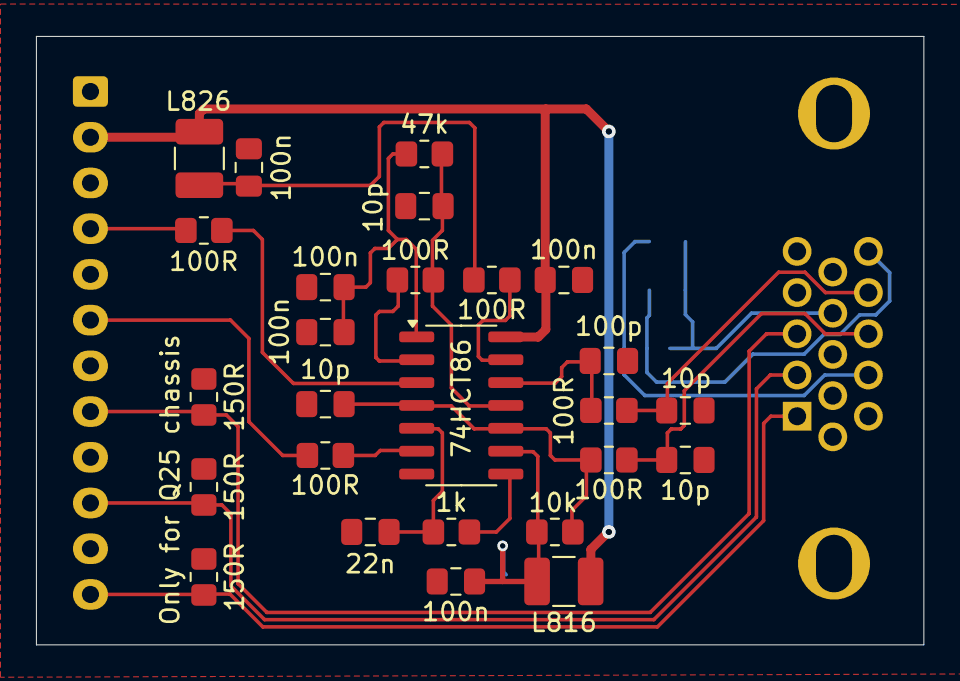
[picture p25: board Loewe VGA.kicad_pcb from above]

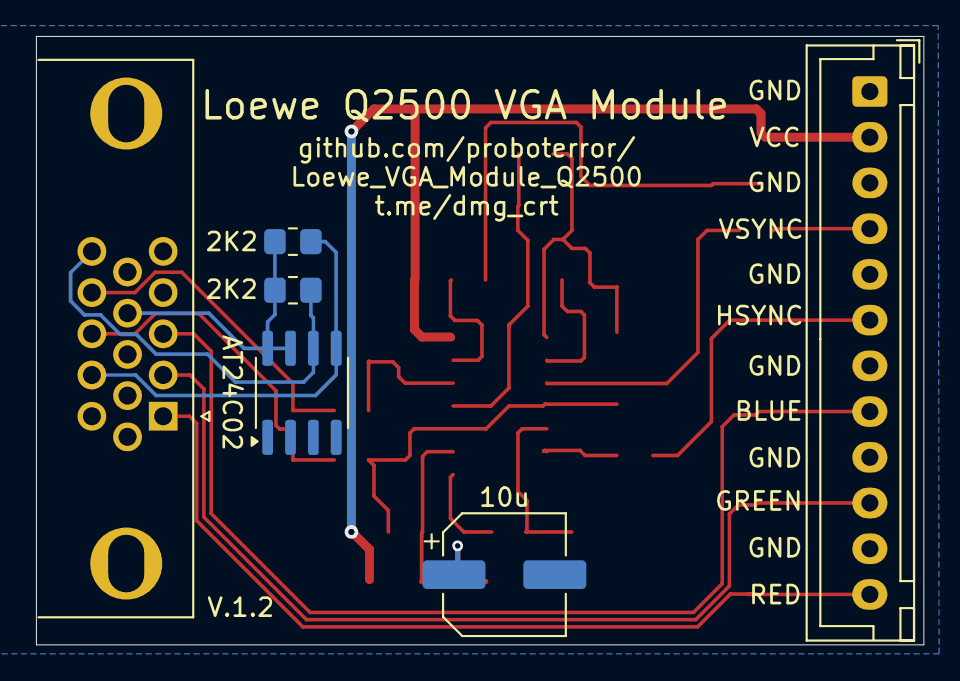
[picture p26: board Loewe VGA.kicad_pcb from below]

Board: 2 copper layers, 49.3 x 33.8 mm, 32 parts (6 on the bottom side), 24 nets.

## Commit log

2025-10-24 Initial KiCad project PCB implementation.
    Original project from https://circuit-board.de/forum/index.php/Thread/28516-WIP-DIY-Loewe-VGA-Modul-Q2500/
    Schematic and PCB imported from Eagle.
    Schematic recreated from service manual.
    Footprints for C, R, 74HCT86, DSUB-15 replaced with standard KiCad ones.
    PCB altered for new footprints. Tracks width increased to 0.2 mm.
    Schematic and PCB checked with Electrical / Design Rules Checker.
    [Loewe VGA.kicad_pcb, Loewe VGA.kicad_sch]
2025-10-24 Alter silkscreen labels.
    [Loewe VGA.kicad_pcb]
2025-10-24 Alter VGA DSUB-15 connector mounting holes.
    [Loewe VGA.kicad_pcb]
2025-10-24 Add gerber fabrication output.
    [Loewe VGA-B_Cu.gbr, Loewe VGA-B_Mask.gbr, Loewe VGA-B_Paste.gbr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]
2025-11-06 Add project title and link to PCB silkscreen.
    [Loewe VGA.kicad_pcb]
2025-11-06 Production gerbers.
    [Loewe VGA-B_Cu.gbr, Loewe VGA-B_Mask.gbr, Loewe VGA-B_Paste.gbr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]
2025-11-13 Connect VGA pin 8 to GND.
    [Loewe VGA.kicad_pcb, Loewe VGA.kicad_sch]
2025-11-13 Add Loewe Q2400 Chassis Service Manual.
2025-11-13 Do not solder R836~R838 RGB input termination resistors for Q2400 chassis. Source: Loewe Q2400 service manual, p.2-22.
    [Loewe VGA.kicad_sch]
2025-11-16 Replace custom 3225 footprint for L826, L816 with standard 1210(3225). Add 4.7uH value for L826, L816 to schematic (use value from Q2300 board).
    [Loewe VGA.kicad_pcb, Loewe VGA.kicad_sch]
2025-11-16 Add telegram channel link. Adjust power tracks width.
    [Loewe VGA.kicad_pcb]
2025-11-16 Add R836~R838 RGB termination resistors note on PCB silkscreen.
    [Loewe VGA.kicad_pcb]
2025-11-16 Add connection diagram for Q2400 chassis.
2025-11-16 Add connection diagram for Q2500 chassis.
2025-11-22 Add non-standard 2.54 mm JST XH S12B connector footprint based on KiCad 2.50 mm one.
2025-11-22 Replace JST XH 2.50 mm with custom 2.54 mm. Remove unused Molex 22-23-2121 footprint. Add version V.1.1 label to PCB silkscreen.
    [Loewe VGA.kicad_pcb, Loewe VGA.kicad_sch]
2025-11-22 Update PCB images.
2025-12-14 Replace incorrect Connector_Dsub:DSUB-15-HD_Male with short Connector_Dsub:DSUB-15-HD_Female. Move VGA and TV connectors to back side. Reduce PCB width. Change VCC tracks width from 0.3 to 0.5 mm. Al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
    PCB version updated to 1.2.
    [Loewe VGA.kicad_pcb, Loewe VGA.kicad_sch]
2025-12-14 Update gerbers.
    [Loewe VGA-B_Cu.gbr, Loewe VGA-B_Mask.gbr, Loewe VGA-B_Paste.gbr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]
2025-12-15 Arrange Q2400 docs, add service manual with signal board schematic.
2025-12-15 Add Q2500 signal boards schematics.
2025-12-15 Add Q2500-M PCB images.
2025-12-15 Add Q2500-H PCB images.
2025-12-15 Add Q2500-B PCB images.
2025-12-15 Add PCB input termination mods description.
2025-12-15 Add PCB service manuals drawings for Q2500-B, Q2500-H.
2026-05-08 Add Q2400 Signal Board PCB image to description.
2026-06-22 Add EDID EEPROM option for 848x480@60Hz mode auto detection with widescreen TVs.
    PCB version 1.2.
    [Loewe VGA.kicad_pcb, Loewe VGA.kicad_sch]
